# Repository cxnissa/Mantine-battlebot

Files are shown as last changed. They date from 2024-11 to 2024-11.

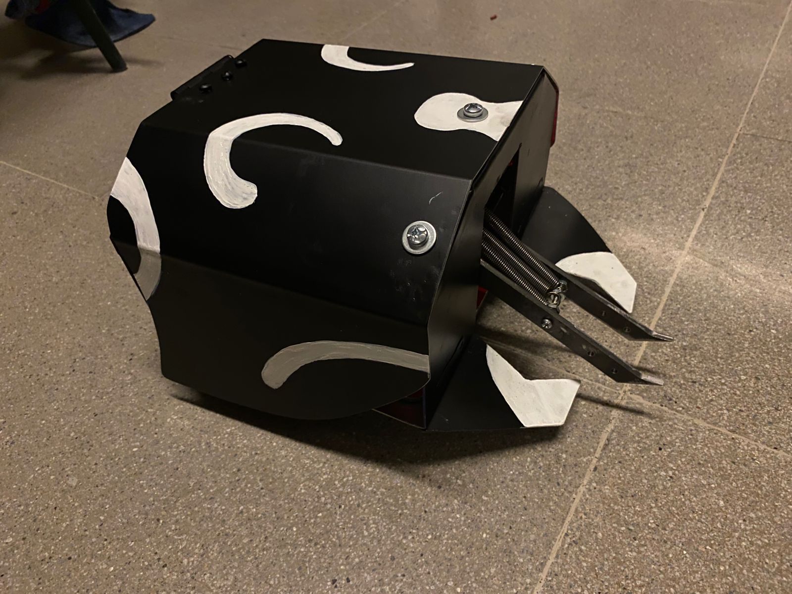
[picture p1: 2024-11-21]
multimedia/mantine_finalizado.jpeg

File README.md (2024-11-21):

# Mantine - 2024

### Historia del Battlebot
Tras el colapso producido por el sistema social y económico del mundo, Raya, una mantarrya robótica, y su fiel compañero Mantis, un camarón mantis con un potente flipper, se enfrentan a la necesidad de mantener y defender el ecosistema del último lugar habitable que les queda, los océanos. Unidas por el poder de la amistad que han llegado a experimentar al enfrentar esta situación, Raya y Mantis se vuelven Mantine para poder defender la biodiversidad de aquel arrecife que han decidido llamar hogar.

mantine_finalizado

## Integrantes
- Constanza Torres - Facultad de Ciencias Físicas y Matemáticas
- Antonia Salazar - Facultad de Ciencias Físicas y Matemáticas
- Beatriz Toledo - Facultad de Ciencias Físicas y Matemáticas
- Benjamin Sanchez - Facultad de Ciencias Físicas y Matemáticas

## Descripción del proyecto
  
### Estrategia utilizada
  
#### Ofensiva
El arma utilizada para el robot es un "Flipper". El objetivo de este es voltear el objetivo, asi como de generarle daño mecanico si no logra realizar lo primero. El funcionamiento de esta arma es bastante sencillo, consta de un brazo metalico, el cual es el encargado de generar el daño al contrincante, esto mediante un resorte conectado a la base del robot. El mecanismo como tal consta de un motor dc con una caja reductora, el cual, mediante una pieza con forma de caparazon de caracol, estira y dobla el resorte conectado al brazo hasta que este quede lo mas abajo posible ( parecido al funcionamiento de un sube y baja), luego, mediante el controlador, se libera el resorte, el cual vuelve a su largo original, levantado el brazo con fuerza. A lo anterior tambien hay que agregarle una cola puntiaguda en la parte posterior del robot la cual actua como defensa, pero debido a la velocidad que puede alcanzar, es posible utilizarla como una especie de lanza.  

#### Defensiva
La defensa del robot es bastante sencilla, consta de la ya mencionada cola, en conjunto con un revestimiento de alucom en forma de mantarraya, el cual cubre todo el robot menos el arma. Donde tambien es importante mencionar la capacidad de cambiar velocidades que introdujimos al bot, lo cual le permite ser mas impredecible en sus movimientos.

### Diagrama funcional
Diagrama de cajas

## Licencia
<br />Esta obra está bajo una <a rel="license" href="http://creativecommons.org/licenses/by-nc/4.0/">Licencia Creative Commons Atribución-NoComercial 4.0 Internacional</a>.

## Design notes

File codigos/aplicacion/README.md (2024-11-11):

# Código de la Aplicación

Layout de la aplicación para quienes tengan de mano hábil la derecha:
Captura de Pantalla 2024-11-11 a la(s) 20 37 18

Versión para zurdos:
Captura de Pantalla 2024-11-11 a la(s) 20 38 22

El layout de la aplicación esta pensado para controlar el joystick con la mano hábil pues es lo que requiere movimientos más finos, movimientos hacia adelante y hacia atrás en este joystick hacen al robot acelerar y retroceder, mientras que mover el joystick hacia los costados hace girar al robot.

Los botones ubicados en el lado opuesto al joystick funcionan de tal manera que puedan ser apretados de manera cómoda mientras se usa el joystick.

Además la aplicación cuenta con una guía de uso para facilitar su accesibilidad.
Captura de Pantalla 2024-11-11 a la(s) 20 41 53
Captura de Pantalla 2024-11-11 a la(s) 20 42 05

Para conectarse a la aplicación es necesario descargarse RemoteXY y escanear el siguiente codigo QR con el celular conectado al wifi proveniente de la ESP8266.

Captura de Pantalla 2024-11-11 a la(s) 20 36 51

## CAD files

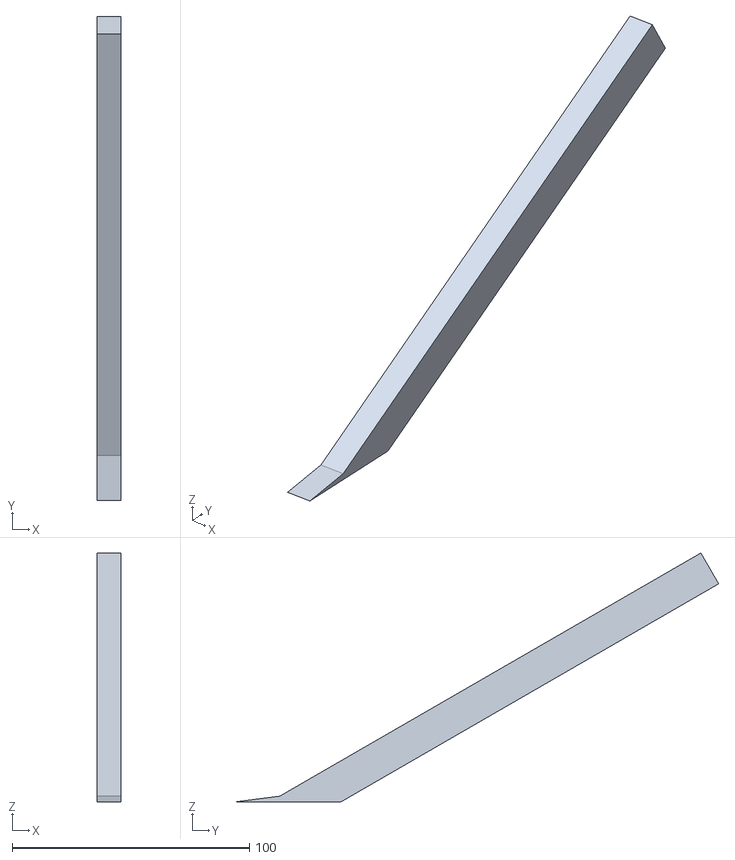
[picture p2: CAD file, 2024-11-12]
planos/flipper.stl
10.0 x 204.2 x 105.0

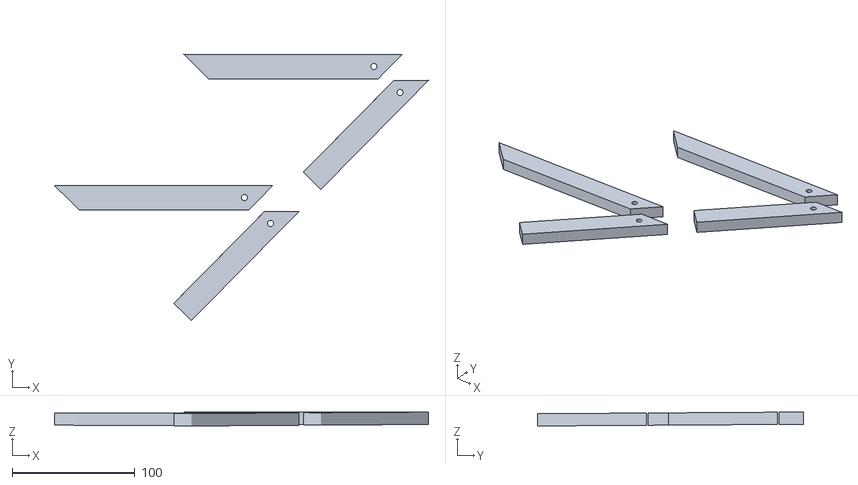
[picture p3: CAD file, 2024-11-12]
planos/soporte v1.stl
304.4 x 216.7 x 11.4

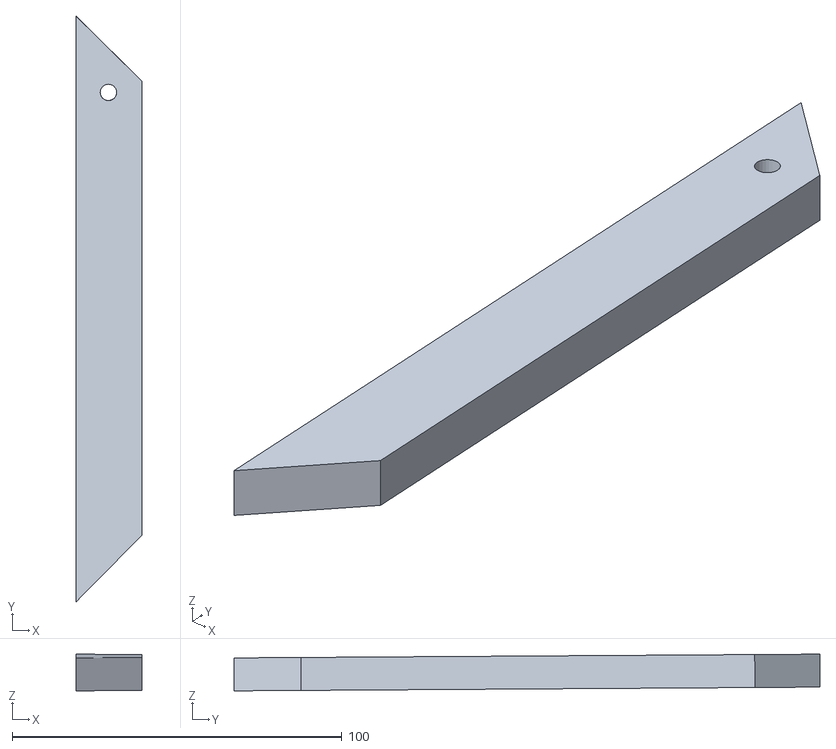
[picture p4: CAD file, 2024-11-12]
planos/Cuerpo3.stl
20.0 x 177.8 x 11.1

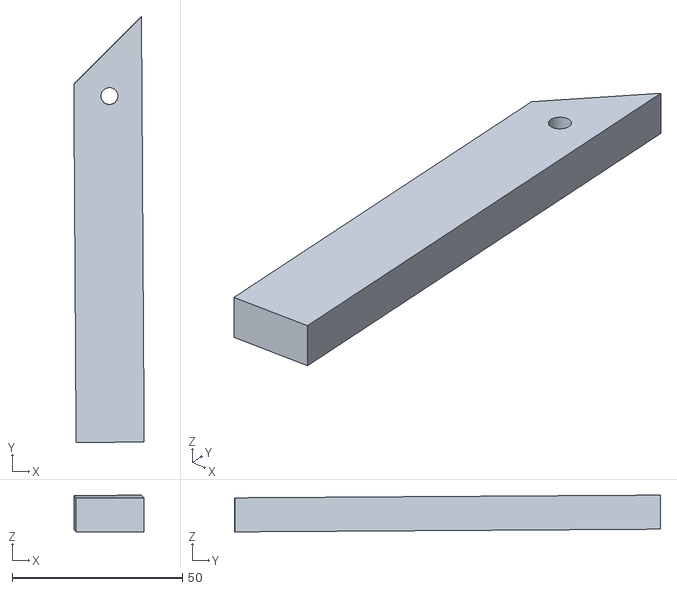
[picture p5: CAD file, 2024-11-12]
planos/Cuerpo1.stl
20.7 x 125.0 x 10.8

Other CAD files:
planos/base v1.f3d

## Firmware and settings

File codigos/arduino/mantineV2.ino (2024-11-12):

#define REMOTEXY_MODE__WIFI_POINT

#include <ESP8266WiFi.h>
#include <RemoteXY.h>

// Nombre del wifi y contraseña
const char* ssid = "bulbasaur";
const char* password = "pikachu12";
WiFiServer server(80);

// Pins del puente H
const int PWMA = 15;
const int AIN1 = 14;
const int AIN2 = 12;
const int PWMB = 13;
const int BIN1 = 4;
const int BIN2 = 5;
const int arma = 0;


// RemoteXY GUI configuration  
#pragma pack(push, 1)  
uint8_t RemoteXY_CONF[] =   // 1585 bytes
  { 255,16,0,0,0,42,6,19,0,0,0,98,117,108,98,97,115,97,117,114,
  0,16,2,106,200,200,80,7,0,0,1,0,0,0,0,17,0,5,6,15,
  150,150,127,12,52,52,32,186,198,31,1,26,18,60,60,59,29,21,21,0,
  197,244,83,84,79,80,0,1,21,23,60,60,22,22,25,9,2,129,244,0,
  129,248,105,73,30,21,14,26,8,64,244,84,85,82,66,79,0,129,249,103,
  73,30,54,32,6,15,0,129,40,0,129,47,130,13,38,80,32,6,15,0,
  129,41,0,129,3,95,73,30,116,33,8,12,64,127,226,134,186,0,129,2,
  90,73,30,180,33,8,12,64,127,226,134,187,0,129,0,105,73,30,148,6,
  13,13,64,244,226,140,131,0,129,75,50,24,33,149,58,9,14,64,244,226,
  140,132,0,129,248,148,73,30,49,18,4,12,64,244,33,0,129,19,33,8,
  30,16,16,3,12,64,244,194,161,0,129,255,80,73,30,14,39,8,15,64,
  198,226,134,165,0,129,248,130,40,20,22,39,16,8,64,199,70,76,73,80,
  0,131,29,30,21,35,87,2,13,12,2,16,2,31,226,154,153,239,184,143,
  0,154,42,131,40,15,8,38,102,2,12,12,2,16,16,244,63,0,106,42,
  2,0,103,23,55,22,47,29,14,0,199,26,16,16,79,78,0,79,70,70,
  0,20,0,5,20,35,130,130,16,14,52,52,32,186,198,31,1,29,125,60,
  60,131,40,21,21,0,197,244,83,84,79,80,0,1,12,52,13,23,145,21,
  25,9,2,129,244,0,1,14,102,7,68,165,38,14,27,1,187,31,0,129,
  243,33,64,20,144,13,26,8,64,244,84,85,82,66,79,0,129,45,137,13,
  38,126,43,6,15,0,129,40,0,129,60,137,14,38,152,43,6,15,0,129,
  41,0,129,93,88,19,30,6,34,8,12,64,127,226,134,186,0,129,59,88,
  19,30,69,34,8,12,64,127,226,134,187,0,129,71,20,31,33,37,8,13,
  13,64,244,226,140,131,0,129,75,150,22,35,38,60,9,14,64,244,226,140,
  132,0,129,24,43,8,30,172,17,4,12,64,244,33,0,129,6,38,8,30,
  140,15,3,12,64,244,194,161,0,129,4,115,28,45,167,43,11,18,64,196,
  226,134,165,0,129,18,103,12,20,181,38,5,8,64,199,70,0,129,18,120,
  11,20,181,45,5,8,64,199,76,0,129,20,138,6,20,181,52,3,8,64,
  199,73,0,129,17,155,13,20,180,58,6,8,64,199,80,0,131,47,10,7,
  30,87,2,13,12,2,16,2,31,226,154,153,239,184,143,0,154,42,131,55,
  10,6,30,102,2,12,12,2,16,16,244,63,0,106,42,3,0,131,27,108,
  21,35,49,39,48,16,2,254,244,31,105,122,113,117,105,101,114,100,97,0,
  166,42,131,49,80,21,35,102,39,45,16,2,114,104,31,100,101,114,101,99,
  104,97,0,169,42,129,18,43,73,30,66,25,60,12,64,27,109,97,110,111,
  32,104,195,161,98,105,108,0,5,0,131,35,88,21,35,81,24,40,14,2,
  115,90,31,106,111,121,115,116,105,99,107,0,170,41,129,11,28,73,30,78,
  10,46,12,64,187,72,79,87,32,84,79,0,131,44,50,21,35,81,40,40,
  14,2,198,213,31,115,116,111,112,0,170,38,131,44,93,21,35,81,56,40,
  14,2,254,255,31,116,117,114,98,111,0,170,26,131,9,35,21,35,4,4,
  14,13,2,243,254,31,226,156,150,0,154,0,11,0,5,233,18,150,150,44,
  28,38,38,0,244,26,31,129,73,20,19,33,59,23,13,13,64,244,226,140,
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

// this structure defines all the variables and events of your control interface 
struct {

  // input variables
  int8_t joystick_x; // from -100 to 100
  int8_t joystick_y; // from -100 to 100
  uint8_t STOP; // =1 if button pressed, else =0
  uint8_t TURBO; // =1 if button pressed, else =0
  uint8_t FLIP; // =1 if ON, else =0
  int8_t zjoystick_x; // from -100 to 100
  int8_t zjoystick_y; // from -100 to 100
  uint8_t zSTOP; // =1 if button pressed, else =0
  uint8_t zTURBO; // =1 if button pressed, else =0
  uint8_t zFLIP; // =1 if button pressed, else =0

} RemoteXY;   

void Wheel(unsigned char *motor, int pwrPin, int v) {
  // Limitar el valor de v entre -100 y 100
  if (v > 100) v = 100;
  if (v < -100) v = -100;

  int speed = abs(v) * 2.55; // Convertir el rango de -100 a 100 a 0-255 para PWM

  if (v > 10) { 
    digitalWrite(motor[0], HIGH);   // Adelante
    digitalWrite(motor[1], LOW);
    analogWrite(pwrPin, speed);     // Controlar la velocidad con PWM 
  } 
  else if (v < -10) { 
    digitalWrite(motor[0], LOW);    // Atrás
    digitalWrite(motor[1], HIGH);
    analogWrite(pwrPin, speed);     // Controlar la velocidad con PWM
  } 
  else {
    digitalWrite(motor[0], LOW);    // Parar
    digitalWrite(motor[1], LOW);
    analogWrite(pwrPin, 0);         // Detener el motor
  }
}

/* defined two arrays with a list of pins for each motor */
unsigned char RightMotor[2] = 
  {AIN1, AIN2};
unsigned char LeftMotor[2] = 
  {BIN1, BIN2};



void ControlMotors(int x, int y) {
  int turn = x;           // Forward/Backward
  int forward = y;              // Left/Right
  
  // Apply a threshold for turning sensitivity
  if (abs(turn) < 10) {
    turn = 0;                // Ignore small turn values within -10 to 10
  } else {
    turn = 0.7 * turn;     
  }

  float speedMultiplier = (RemoteXY.TURBO > 0 || RemoteXY.zTURBO > 0) ? 1 : 0.5;

  // Control right motor (PWMA for speed)
  Wheel(RightMotor, PWMA, speedMultiplier * (forward - turn));

  // Control left motor (PWMB for speed)
  Wheel(LeftMotor, PWMB, speedMultiplier * (forward + turn));
}



#pragma pack(pop)
 



void setup() {
  // put your setup code here, to run once:
  {
  remotexy = new CRemoteXY (
    RemoteXY_CONF_PROGMEM, 
    &RemoteXY, 
    new CRemoteXYConnectionServer (
      new CRemoteXYComm_WiFiPoint (
        "bulbasaur",       // REMOTEXY_WIFI_SSID
        "pikachu12"),        // REMOTEXY_WIFI_PASSWORD
      6377                  // REMOTEXY_SERVER_PORT
    )
  ); 
  } 
  
  Serial.begin(115200); // Start the serial monitor.
   Serial.println("Connect to WIFI");
   Serial.println(String(RemoteXY.joystick_y - RemoteXY.joystick_x));
  delay(20);
  pinMode (AIN1, OUTPUT);
  pinMode (AIN2, OUTPUT);
  pinMode (BIN1, OUTPUT);
  pinMode (BIN2, OUTPUT);
  pinMode (arma, OUTPUT);


  digitalWrite(AIN1, LOW);
  digitalWrite(AIN2, LOW);
  digitalWrite(BIN1, LOW);
  digitalWrite(BIN2, LOW);

  
}

void loop() {
  RemoteXY_Handler();

  if (RemoteXY.FLIP == 1) {  // Check for FLIP button
    analogWrite(arma,255);
  } else  {
  analogWrite(arma,0);
 }

  if (RemoteXY.STOP > 0 || RemoteXY.zSTOP > 0) {  // Check for STOP button
    digitalWrite(AIN1, LOW);
    digitalWrite(AIN2, LOW);
    digitalWrite(BIN1, LOW);
    digitalWrite(BIN2, LOW);
    analogWrite(PWMA, 0);
    analogWrite(PWMB, 0); 
    return;
  }


    // Only use zjoystick if main joystick is inactive
  if (abs(RemoteXY.joystick_x) > 10 || abs(RemoteXY.joystick_y) > 10) {
    ControlMotors(RemoteXY.joystick_x, RemoteXY.joystick_y);
  } else {
    ControlMotors(RemoteXY.zjoystick_x, RemoteXY.zjoystick_y);
  }

  }

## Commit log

2024-11-12 Rename Captura de Pantalla 2024-11-11 a la(s) 20.59.12.png to prototipo carton
2024-11-12 Rename Captura de Pantalla 2024-11-11 a la(s) 20.59.24.png to vista superior avance arma
2024-11-12 Rename Captura de Pantalla 2024-11-11 a la(s) 21.55.17.png to vista lateral avance arma
2024-11-12 Rename Captura de Pantalla 2024-11-11 a la(s) 21.57.56.png to vista angulo superior
2024-11-12 Rename Captura de Pantalla 2024-11-11 a la(s) 21.58.50.png to partes arma
2024-11-12 Rename Captura de Pantalla 2024-11-11 a la(s) 21.58.18.png to vista superior
2024-11-12 Rename Captura de Pantalla 2024-11-11 a la(s) 21.58.03.png to vista lateral
2024-11-12 Add files via upload
    actualizacion codigo tras implementar flipper a la aplicacion
    [mantineV2.ino]
